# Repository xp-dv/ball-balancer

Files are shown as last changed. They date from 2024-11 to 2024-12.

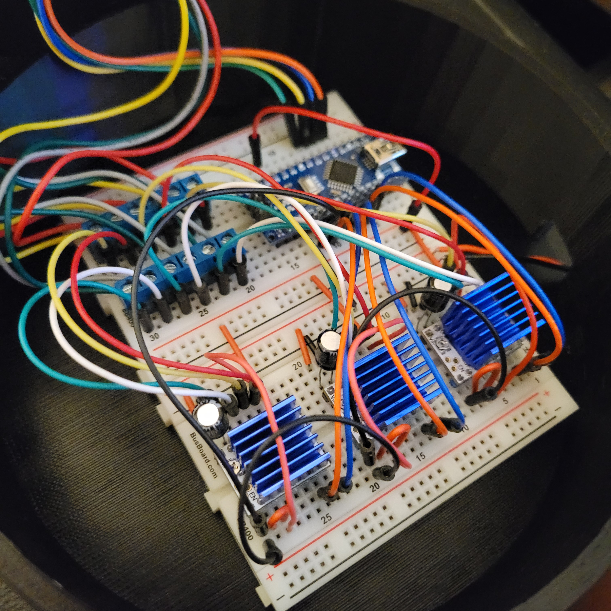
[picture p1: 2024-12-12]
circuit_design/breadboard_build.jpg

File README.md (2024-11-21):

# Ball Balancer
3-RRS parallel manipulator that balances a steel ball atop a large resistive touch screen platform.

## Basic Features
- Built to balance and position a single 1.5" steel ball.
- 8.4" diagonal operational area.
- Software powered by the STM32 NUCLEO-F411RE microcontroller.
- Stable and precise 3-RRS parallel manipulator design.
- Requires 12V, 24W power supply.

## Detailed Information
- Platform motion driven by three [Adafruit](https://www.adafruit.com/) [12V stepper motors](https://www.adafruit.com/product/324).
- Stepper motors driven by three [ST](https://www.st.com/content/st_com/en.html) [X-NUCLEO-IHM03A1](https://www.st.com/en/ecosystems/x-nucleo-ihm03a1.html) high-power stepper motor driver expansion boards for the STM32 Nucleo-64 family of microcontrollers.
- Ball position measured by [VSDISPLAY](https://www.amazon.com/stores/VSDISPLAY/VSDISPLAY/page/DE75699F-7981-4B21-AC69-5A6736383F62) [8.4" Resistive Touch Screen](https://a.co/d/e97aLYa).
- 3D printed body is a custom modified version for ease of manufacture and assembly of the [3-RRS Parallel Manipulator by Aaed Musa](https://myhub.autodesk360.com/ue2bd9d7f/g/shares/SH512d4QTec90decfa6e8a1bdd403930aff7).
- Assembled with M3 and M4 metal hardware.
- Developed in VS Code and STM32CubeIDE.

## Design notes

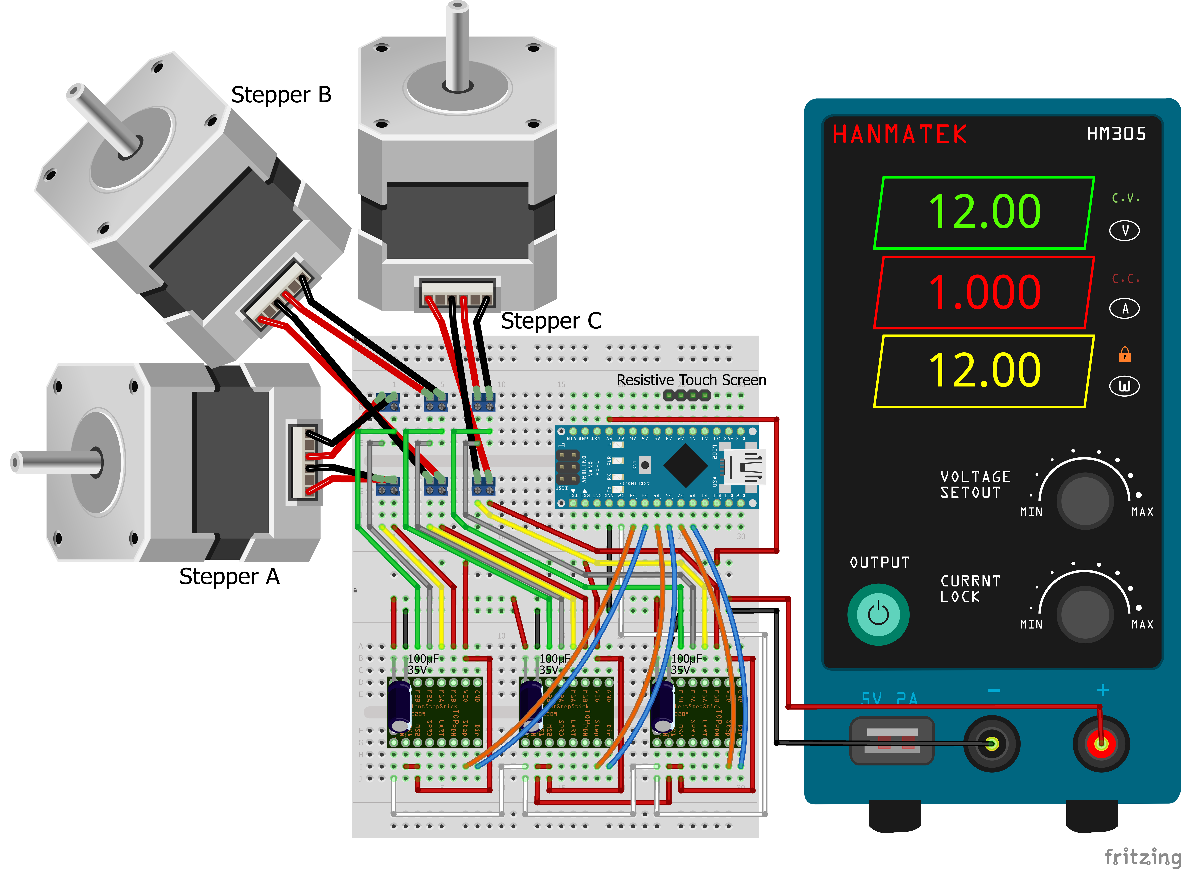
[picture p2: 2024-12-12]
circuit_design/breadboard_schematic.png

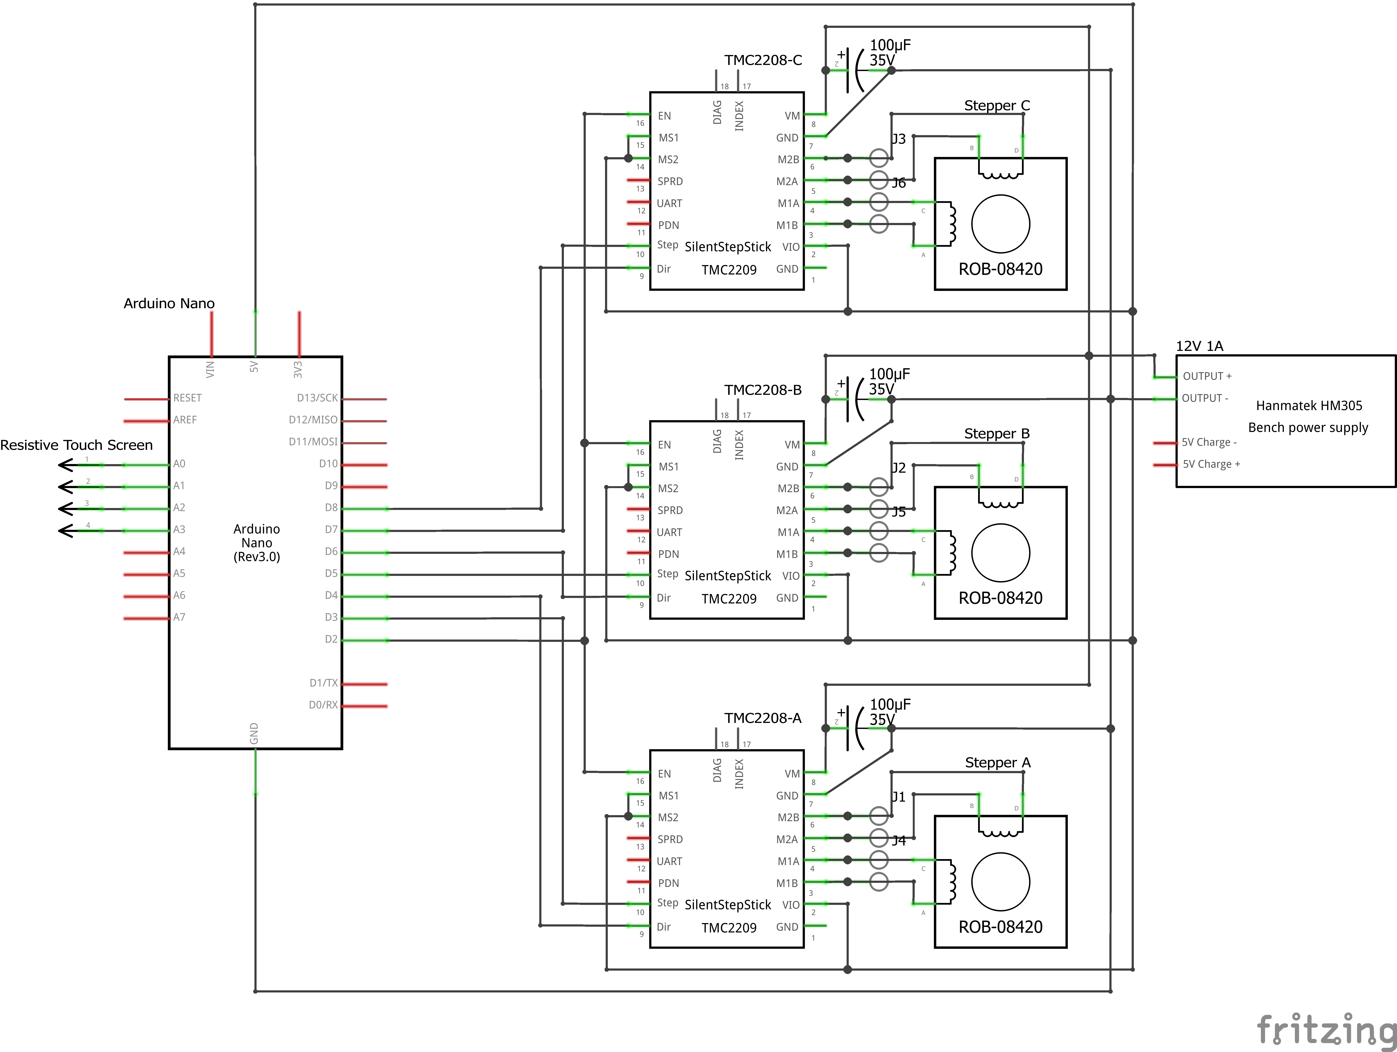
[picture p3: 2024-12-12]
circuit_design/circuit_schematic.png

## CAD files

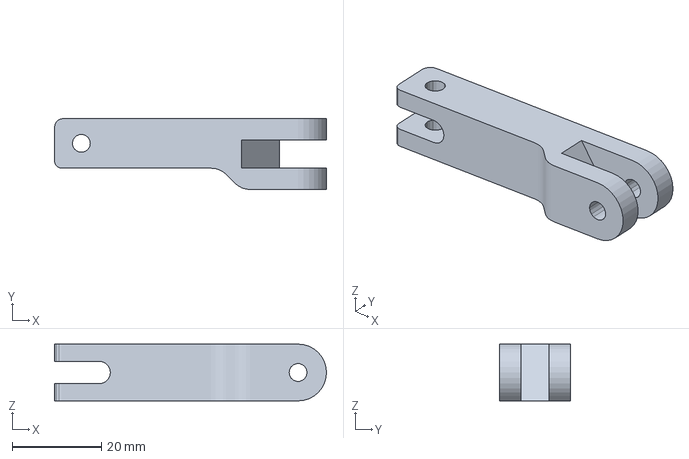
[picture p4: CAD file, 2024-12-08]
chassis/link_1 (original).3mf
60.8 x 15.9 x 12.7 mm

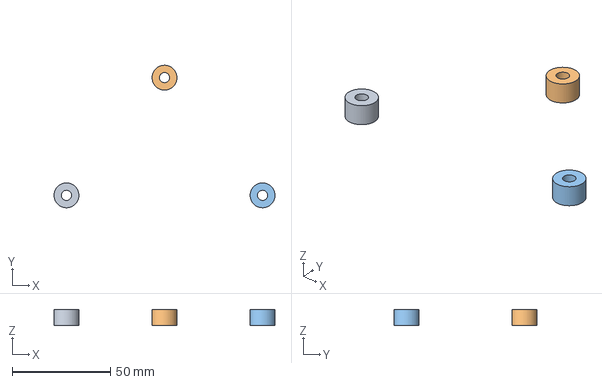
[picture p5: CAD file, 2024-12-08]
chassis/spacer (x3).3mf
112.7 x 72.7 x 8.32 mm

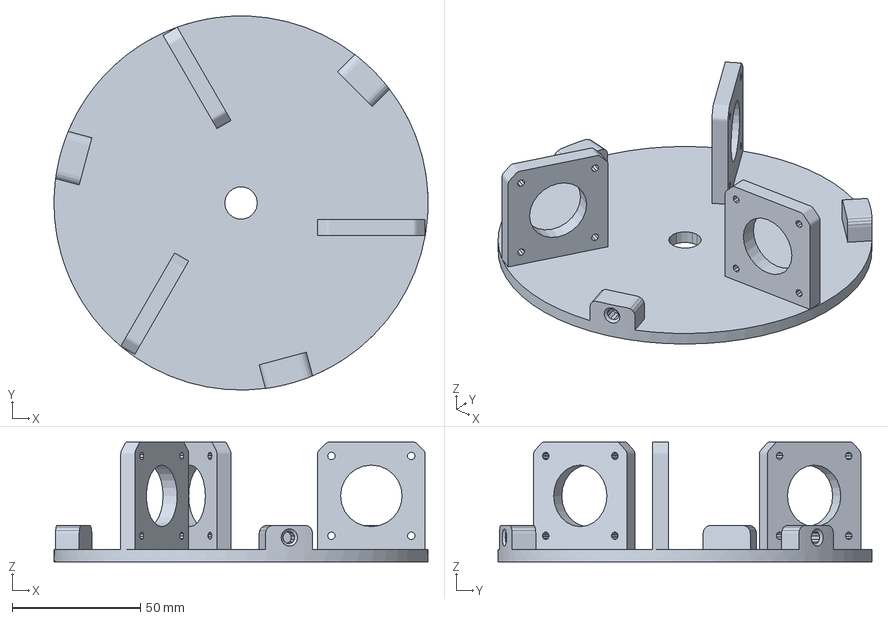
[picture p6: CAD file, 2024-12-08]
chassis/base_plate (no_inlay).3mf
145.8 x 145.8 x 46.8 mm

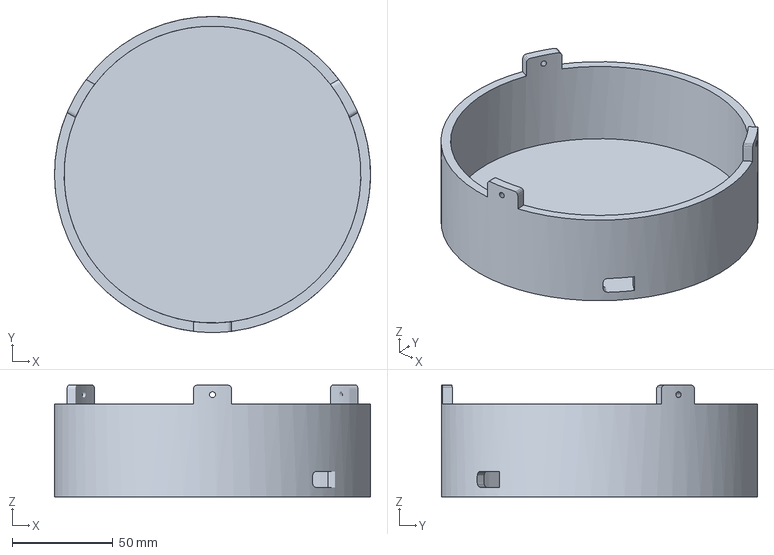
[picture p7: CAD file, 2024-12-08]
chassis/base_stand (no_pegs).3mf
156.9 x 156.9 x 55.6 mm

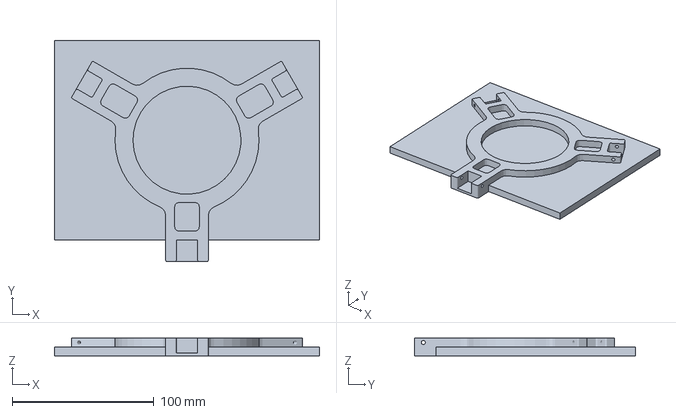
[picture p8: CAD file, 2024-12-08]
chassis/platform_frame (original).3mf
187.0 x 156.2 x 12.7 mm

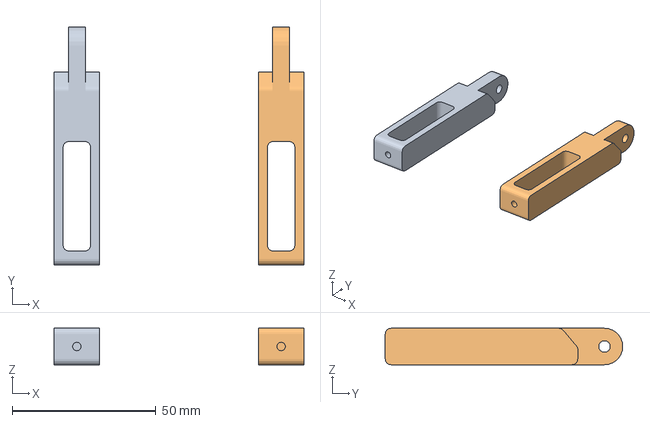
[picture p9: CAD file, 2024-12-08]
chassis/link_2.3mf
86.9 x 82.5 x 12.7 mm

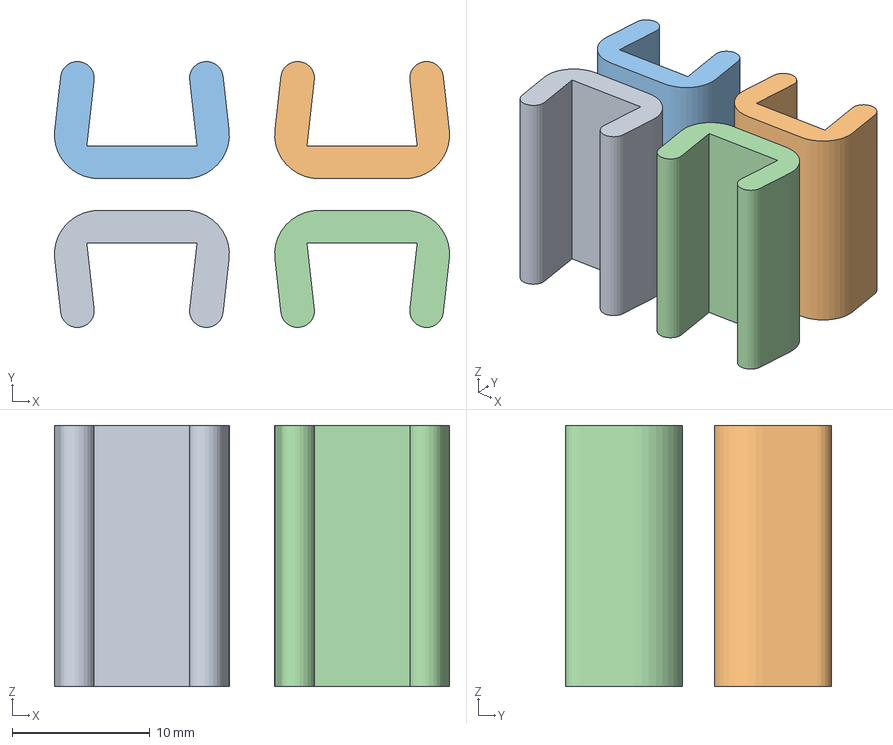
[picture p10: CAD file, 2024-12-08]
chassis/retainer_clip (x4) (widened).3mf
28.7 x 19.3 x 19.0 mm

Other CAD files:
chassis/link_1 (deeper_channel).stl
chassis/platform_frame (teardrop_holes).stl
chassis/base_plate (no_inlay).stl
chassis/base_stand (no_pegs).stl

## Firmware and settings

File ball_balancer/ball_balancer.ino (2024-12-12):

#include <AccelStepper.h>
#include <MultiStepper.h>
#include <TouchScreen.h>
#include <stdint.h>
#include <math.h>

//* User Definitions
// PID
#define KP 17E-5
#define KI 1E-7
#define KD 4E-3
#define KS 15
// Misc
#define HOME_HEIGHT 4.25
#define BAUD_RATE 115200

// Pin Assignment
enum pins {
  // TMC2208 Stepper Motor Drivers
  ENABLE_PIN = 2, // Enable (EN) Pin
  STEP_PIN_A = 3, // Stepper A Step Signal (STEP)
  DIR_PIN_A  = 4, // Stepper A Direction Signal (DIR)
  STEP_PIN_B = 5, // Stepper B Step Signal (STEP)
  DIR_PIN_B  = 6, // Stepper B Direction Signal (DIR)
  STEP_PIN_C = 7, // Stepper C Step Signal (STEP)
  DIR_PIN_C  = 8,  // Stepper C Direction Signal (DIR)
  Y_PLUS_PIN  = A0, // Resistive Touch Screen
  X_PLUS_PIN  = A1, // Resistive Touch Screen
  Y_MINUS_PIN = A2, // Resistive Touch Screen
  X_MINUS_PIN = A3, // Resistive Touch Screen
};

//* Private Definitions
// Leg Assignment
enum legs {
  LEG_A,
  LEG_B,
  LEG_C,
};

// Declare inverse kinematics class
class inv_kinematics {
  public:
    inv_kinematics(double _d, double _e, double _f, double _g);
    double theta(int leg, double h_z, double n_x, double n_y);
  private:
    double d, e, f, g;  // Parameters
};

// Define inverse kinematics class primary function
inv_kinematics::inv_kinematics(double _d, double _e, double _f, double _g) {
  d = _d;
  e = _e;
  f = _f;
  g = _g;
}

// Define inverse kinematics class theta
double inv_kinematics::theta(int leg, double h_z, double n_x, double n_y) {
  double n_mag = sqrt(pow(n_x, 2) + pow(n_y, 2) + 1);
  n_x /= n_mag;
  n_y /= n_mag;
  double n_z = 1 / n_mag;

  double x, y, z, mag, angle;
  switch (leg) {
    case LEG_A:
      y = d + (e / 2) * (1 - (pow(n_x, 2) + 3 * pow(n_z, 2) + 3 * n_z) /
          (n_z + 1 - pow(n_x, 2) + (pow(n_x, 4) - 3 * pow(n_x, 2) * pow(n_y, 2)) /
          ((n_z + 1) * (n_z + 1 - pow(n_x, 2)))));
      z = h_z + e * n_y;
      mag = sqrt(pow(y, 2) + pow(z, 2));
      angle = acos(y / mag) + acos((pow(mag, 2) + pow(f, 2) - pow(g, 2)) / (2 * mag * f));
      break;
    case LEG_B:
      x = (sqrt(3) / 2) * (e * (1 - (pow(n_x, 2) + sqrt(3) * n_x * n_y) / (n_z + 1)) - d);
      y = x / sqrt(3);
      z = h_z - (e / 2) * (sqrt(3) * n_x + n_y);
      mag = sqrt(pow(x, 2) + pow(y, 2) + pow(z, 2));
      angle = acos((sqrt(3) * x + y) / (-2 * mag)) + acos((pow(mag, 2) + pow(f, 2) - pow(g, 2)) / (2 * mag * f));
      break;
    case LEG_C:
      x = (sqrt(3) / 2) * (d - e * (1 - (pow(n_x, 2) - sqrt(3) * n_x * n_y) / (n_z + 1)));
      y = -x / sqrt(3);
      z = h_z + (e / 2) * (sqrt(3) * n_x - n_y);
      mag = sqrt(pow(x, 2) + pow(y, 2) + pow(z, 2));
      angle = acos((sqrt(3) * x - y) / (2 * mag)) + acos((pow(mag, 2) + pow(f, 2) - pow(g, 2)) / (2 * mag * f));
      break;
  }
  return (angle * (180 / PI)); // Convert to degrees
}

// Create inverse kinematics instance
inv_kinematics inv_kinematics(2, 3.125, 1.75, 3.669291339);

// Create touch screen instance
TouchScreen ts = TouchScreen(X_PLUS_PIN, Y_PLUS_PIN, X_MINUS_PIN, Y_MINUS_PIN, 0);

// Create stepper motor instances
const int DRIVER_TYPE = 1; // Normal
// AccelStepper stepper_name(DRIVER_TYPE, STEP_PIN, DIR_PIN);
AccelStepper stepperA(DRIVER_TYPE, STEP_PIN_A, DIR_PIN_A);
AccelStepper stepperB(DRIVER_TYPE, STEP_PIN_B, DIR_PIN_B);
AccelStepper stepperC(DRIVER_TYPE, STEP_PIN_C, DIR_PIN_C);

// Create MultiStepper instance for AccelStepper instances
MultiStepper steppers;

// Global variables
long int pos[3];
double angle_origin = 206.662752199;
double speed[3] = {0, 0, 0};
double speed_previous[3];
double x_offset = 500;
double y_offset = 500;
double error[2] = {0, 0};
double error_previous[2];
double integral[2] = {0, 0};
double derivative[2] = {0, 0};
double out[2];
long time_i;
double angle_to_step = 3200 / 360;
bool detected = 0;

void setup() {
  Serial.begin(BAUD_RATE);

  // Initialize steppers
  steppers.addStepper(stepperA);
  steppers.addStepper(stepperB);
  steppers.addStepper(stepperC);

  // Set enable pin
  pinMode(ENABLE_PIN, OUTPUT);
  digitalWrite(ENABLE_PIN, HIGH);
  delay(1000);
  digitalWrite(ENABLE_PIN, LOW);

  // Go to home position
  move(HOME_HEIGHT, 0, 0);
  steppers.runSpeedToPosition();
}

void loop() {
  PID(0, 0);
}

void move(double h_z, double n_x, double n_y) {
  if (detected) {
    for (int i = 0; i < 3; i++) {
      pos[i] = round((angle_origin - inv_kinematics.theta(i, h_z, n_x, n_y)) * angle_to_step);
    }
    stepperA.setMaxSpeed(speed[LEG_A]);
    stepperB.setMaxSpeed(speed[LEG_B]);
    stepperC.setMaxSpeed(speed[LEG_C]);
    stepperA.setAcceleration(speed[LEG_A] * 30);
    stepperB.setAcceleration(speed[LEG_B] * 30);
    stepperC.setAcceleration(speed[LEG_C] * 30);
    stepperA.moveTo(pos[LEG_A]);
    stepperB.moveTo(pos[LEG_B]);
    stepperC.moveTo(pos[LEG_C]);
    stepperA.run();
    stepperB.run();
    stepperC.run();
  } else {
    for (int i = 0; i < 3; i++) {
      pos[i] = round((angle_origin - inv_kinematics.theta(i, h_z, 0, 0)) * angle_to_step);
    }
    stepperA.setMaxSpeed(800);
    stepperB.setMaxSpeed(800);
    stepperC.setMaxSpeed(800);
    steppers.moveTo(pos);
    steppers.run();
  }
}

void PID(double setpoint_X, double setpoint_Y) {
  TSPoint p = ts.getPoint();
  if (p.x != 0) {
    detected = 1;
    for (int i = 0; i < 2; i++) {
      error_previous[i] = error[i];
      error[i] = (i == 0) * (x_offset - p.x - setpoint_X) + (i == 1) * (y_offset - p.y - setpoint_Y);
      integral[i] += error[i] + error_previous[i];
      derivative[i] = error[i] - error_previous[i];
      derivative[i] = isnan(derivative[i]) || isinf(derivative[i]) ? 0 : derivative[i];
      out[i] = KP * error[i] + KI * integral[i] + KD * derivative[i];
      out[i] = constrain(out[i], -0.25, 0.25);
    }
    for (int i = 0; i < 3; i++) {
      speed_previous[i] = speed[i];
      speed[i] = (i == LEG_A) * stepperA.currentPosition() + (i == LEG_B) * stepperB.currentPosition() + (i == LEG_C) * stepperC.currentPosition();
      speed[i] = abs(speed[i] - pos[i]) * KS;
      speed[i] = constrain(speed[i], speed_previous[i] - 200, speed_previous[i] + 200);
      speed[i] = constrain(speed[i], 0, 1000);
    }
    Serial.println((String) "X OUT = " + out[0] + "   Y OUT = " + out[1] + "   Speed A: " + speed[LEG_A]);
  } else {
    delay(10);
    TSPoint p = ts.getPoint();
    if (p.x == 0) {
      detected = 0;
    }
  }
  time_i = millis();
  while (millis() - time_i < 20) {
    move(4.25, -out[0], -out[1]);
  }
}

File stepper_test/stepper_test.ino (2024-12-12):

#include <AccelStepper.h>
#include <MultiStepper.h>

// Pin Assignment
enum pins {
  // TMC2208 Stepper Motor Drivers
  ENABLE_PIN = 2, // Enable (EN) Pin
  STEP_PIN_A = 3, // Stepper A Step Signal (STEP)
  DIR_PIN_A  = 4, // Stepper A Direction Signal (DIR)
  STEP_PIN_B = 5, // Stepper B Step Signal (STEP)
  DIR_PIN_B  = 6, // Stepper B Direction Signal (DIR)
  STEP_PIN_C = 7, // Stepper C Step Signal (STEP)
  DIR_PIN_C  = 8, // Stepper C Direction Signal (DIR)
};

// User Constants
#define HOME_ANGLE 206 // Do not go lower than 200
#define SPEED 200 // Do not exceed 800
#define STEP_SIZE 25
#define NUMBER_OF_STEPS 20

// Create stepper motor instances
const int DRIVER_TYPE = 1; // Normal
// AccelStepper stepper_name(DRIVER_TYPE, STEP_PIN, DIR_PIN);
AccelStepper stepperA(DRIVER_TYPE, STEP_PIN_A, DIR_PIN_A);
AccelStepper stepperB(DRIVER_TYPE, STEP_PIN_B, DIR_PIN_B);
AccelStepper stepperC(DRIVER_TYPE, STEP_PIN_C, DIR_PIN_C);

// Create MultiStepper instance for AccelStepper instances
MultiStepper steppers;

// Stepper home position array
long pos[3] = {HOME_ANGLE, HOME_ANGLE, HOME_ANGLE};

void setup() {
  // Serial.begin(9600);
  //Set iniial maximum speed value for the steppers (steps/sec)
  stepperA.setMaxSpeed(SPEED);
  stepperB.setMaxSpeed(SPEED);
  stepperC.setMaxSpeed(SPEED);
  // Adding the steppers to the steppersControl instance for multi stepper control
  steppers.addStepper(stepperA);
  steppers.addStepper(stepperB);
  steppers.addStepper(stepperC);
  // TMC2208 driver enable pin
  pinMode(ENABLE_PIN, OUTPUT);
  digitalWrite(ENABLE_PIN, LOW);
  delay(1000); // Delay for platform reset
  // Move to home position
  steppers.moveTo(pos);
  // Block CPU until all steppers reach their target position
  steppers.runSpeedToPosition();
}

void loop() {
  const int NUMBER_OF_MOTORS = 3;
  for (int i = 0; i < NUMBER_OF_STEPS; ++i) {
    for (int k = 0; k < NUMBER_OF_MOTORS; ++k) {
      pos[k] += STEP_SIZE;
    }
    steppers.moveTo(pos);
    steppers.runSpeedToPosition();
  }
  for (int i = 0; i < NUMBER_OF_STEPS; ++i) {
    for (int k = 0; k < NUMBER_OF_MOTORS; ++k) {
      pos[k] -= STEP_SIZE;
    }
    steppers.moveTo(pos);
    steppers.runSpeedToPosition();
  }
}

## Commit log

2024-11-22 Create STM32 project
2024-11-22 Initialized all pins needed by IHM03A1 stepper driver
    Due to pinout inconsistency, PA4 is physically jumped to PB6 and PB6 is set to input (aka high-Z, to prevent shorting) so that the SPI Chip Select (aka NSS) signal reaches the stepper motor driver.
2024-12-05 inverse kinematics in main_ball_balancer INO
2024-12-08 Added stepper test program using AccelStepper library
2024-12-08 Added modified .stl and .3mf files for improved printability
    [base_plate (no_inlay).3mf, base_plate (no_inlay).stl, base_stand (no_pegs).3mf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]
2024-12-12 Added circuit design files
    [circuit_design.fzz]
2024-12-12 Minor 3D-print file naming changes
    [base_plate (no_inlay).3mf, base_plate (no_inlay).stl, base_stand (no_pegs).3mf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]
